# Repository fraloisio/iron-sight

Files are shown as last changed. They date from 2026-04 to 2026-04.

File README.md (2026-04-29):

# Iron Sight — Interactive Shooting Gallery

A museum installation where visitors aim a replica rifle at projected targets and pull the trigger. Infrared tracking detects where the gun is pointing and registers hits in a browser-based game. Designed for unattended operation in a public space.

**Created by:** Francesco Aloisio  
**Development assistance:** [Claude](https://claude.ai) (Anthropic)

---

## Table of Contents

1. [How It Works](#how-it-works)
2. [Hardware](#hardware)
3. [Wiring](#wiring)
4. [3D Files & Physical Assembly](#3d-files--physical-assembly)
5. [Space & Projector Setup](#space--projector-setup)
6. [Software Overview](#software-overview)
7. [Pi Setup](#pi-setup)
8. [Connection Modes](#connection-modes)
9. [First-Time Calibration](#first-time-calibration)
10. [Running the System](#running-the-system)
11. [Detection Parameters](#detection-parameters)
12. [Game Configuration](#game-configuration)

---

## How It Works

```
Wii IR bar (2 IR dots, fixed to projected surface)
  ↓  infrared light
Pi Camera v2 NoIR (inside rifle scope, points toward screen)
  ↓  picamera2 + OpenCV blob detection
Raspberry Pi Zero W2 (inside scope body)
  ↓  WebSocket JSON {x, y, shoot}  — port 8765
Browser game (shooting-gallery.html, any device on same network)
  ↓  moves crosshair, calls shoot() on trigger event
Projector → wall
```

The camera detects the two IR dots from the Wii bar and triangulates the midpoint. A homography transform (calibrated per installation) maps camera pixel coordinates to normalised screen coordinates [0–1]. The trigger microswitch sends a `shoot: true` flag via the same WebSocket message.

---

## Hardware

### Components

| Item | Model / Detail |
|---|---|
| Computer | Raspberry Pi Zero W2 |
| Camera | Raspberry Pi NoIR Camera Module v2.1 — 8 MP, 1080p, 75° FOV (IMX219 sensor) |
| IR emitter | Nintendo Wii sensor bar (OEM, USB-powered) |
| Laser pointer | KY-008 650 nm laser module (optional, used during calibration) |
| Trigger | Hinge Lever Micro Switch (NO contact wired to GPIO22) |
| Shutdown button | Momentary push button (wired to GPIO23 and GPIO3) |
| Rifle base | Gevær M/10 (Colt Canada C7 variant, Danish Army service rifle), decommissioned prop |
| Scope housing | 3D-printed faux scope — see `3d-files/` folder |
| Mounting | Picatinny rail system (rifle already had rails fitted) |
| Display | Projector — see [Space & Projector Setup](#space--projector-setup) |

> **Solenoid recoil:** A solenoid actuator was prototyped but removed from the final installation. The code in `ir_detect.py` still contains recoil logic (GPIO27). It is electrically harmless if nothing is wired to GPIO27, but set `RECOIL_ENABLED = False` at the top of `ir_detect.py` to suppress the GPIO output entirely.

---

## Wiring

All wires are soldered directly to the Pi Zero W2 GPIO header pins.

| Physical Pin | GPIO | Wire colour | Role |
|---|---|---|---|
| 2 | 5V | Red | (spare / future use) |
| 5 | GPIO3 | Yellow | Shutdown button — also hardware wake-from-halt |
| 6 | GND | Blue | Shared ground |
| 9 | GND | Green | Spare ground |
| 13 | GPIO27 | White | Recoil relay (unused — solenoid removed) |
| 14 | GND | Green | Trigger ground |
| 15 | GPIO22 | Brown | Trigger microswitch input |
| 16 | GPIO23 | Yellow | Shutdown button (software) |

### Microswitch wiring

| Microswitch terminal | Connects to |
|---|---|
| COM | Green wire → GND (Pin 14) |
| NO (Normally Open) | Brown wire → GPIO22 (Pin 15) |
| NC | Unconnected |

Pulling the trigger closes the NO contact, pulling GPIO22 LOW. The software uses an internal pull-up (`PUD_UP`) and triggers on `FALLING` edge with 120 ms debounce.

### Shutdown button

Two buttons both trigger shutdown. GPIO3 (Pin 5) has a hardware feature: pressing it also **powers the Pi back on** after a halt, so you can use the same button to turn on and off.

---

## 3D Files & Physical Assembly

All CAD and print files are in the `3d-files/` folder:

```
3d-files/
  *.3dm        Rhino source files (editable)
  *.stl        Print-ready STL files
  photos/      Assembly reference photos
```

### Assembly notes

- The scope body is 3D-printed in two halves that clamp around the Pi Zero W2.
- The **camera module** mounts flush at the **objective end** (the end pointing toward the screen/IR bar). The lens faces outward through a hole in the end cap.
- The **push button** (shutdown) mounts at the **eyepiece end** (the end facing the shooter).
- The assembled scope mounts onto the rifle's **Picatinny rail** using a standard rail clamp. No permanent modification to the rifle is required.
- Route the camera ribbon cable internally before closing the housing halves.
- The Pi's USB port (USB OTG) should remain accessible via a cutout for USB connection mode.

---

## Space & Projector Setup

These measurements were validated in the museum installation:

| Parameter | Value |
|---|---|
| Projector distance from wall | 3 m |
| Projector height (lens) | 60 cm from floor |
| Projected surface width | 1.65 m |
| Projected surface height | 1.02 m |
| Bottom edge of projected area | 1.65 m from floor |
| IR bar position | 25 cm below the top edge of the projected area, 60 cm from the top-right corner |
| Shooter position | 5.5 to 6 m from the wall, aligned with the centre of the projected area |

The current version of the software supports the IR bar placed either at the **top or bottom** of the projected area (not just the centre). Adjust the bar position and re-calibrate if the installation geometry differs.

> The IR bar should be USB-powered and fixed securely — any movement invalidates the calibration.

---

## Software Overview

### Files on the Pi (`~/`)

| File | Purpose |
|---|---|
| `ir_detect.py` | **Main process.** IR tracking + trigger + WebSocket server (port 8765). Run this during the game. |
| `preview.py` | **Calibration tool.** Live MJPEG preview at port 8080 with parameter sliders. Run this when setting up or re-calibrating. |
| `ironside-shutdown.py` | **Shutdown daemon.** Watches GPIO23 and GPIO3; halts the Pi on button press. Should always be running. |
| `ironside-portal.py` | **WiFi portal.** Runs when Pi is in hotspot mode; lets you connect the Pi to a WiFi network via a browser. |
| `calibration.json` | Homography matrix saved by `preview.py`. Loaded automatically by `ir_detect.py`. |
| `params.json` | Detection parameters saved by `preview.py`. Loaded automatically by `ir_detect.py`. |

### Files on the game device (laptop/Mac)

| File | Purpose |
|---|---|
| `shooting-gallery.html` | Main game — open in any browser |
| `config.js` | WebSocket connection config (Pi hostname and port). Edit this if the Pi's hostname or IP changes. |
| `ironside-manual.html` | Full operation manual. Serve locally with `python3 -m http.server 8080` to use the 3D viewer. |

`shooting-gallery.html` is fully self-contained — no server, no internet, no dependencies. Open directly in a browser.

### Architecture note

`ir_detect.py` and `ironside-shutdown.py` are independent processes. Run both in separate terminal sessions (or as systemd services — see [Running the System](#running-the-system)).

---

## Pi Setup

### OS

**Use Raspberry Pi OS Lite 32-bit** (not 64-bit).  
The 64-bit variant has a known NetworkManager bug that breaks WPA2 WiFi (`key-mgmt` negotiation fails). 32-bit works correctly.

Flash with Raspberry Pi Imager. Enable SSH and set hostname to `scope` in the imager's advanced options.

A pre-built image of a working installation is available at `archive/scope-backup-2026-04-28.img.gz`. Flash it directly — Raspberry Pi Imager can handle `.img.gz` without decompressing.

### Python dependencies

```bash
sudo apt update
sudo apt install -y python3-picamera2 python3-opencv python3-numpy python3-websockets
```

### Repository

```bash
git clone <repo-url>
# or copy the files manually via scp
```

The scripts expect to live in `~/` (home directory). `calibration.json` and `params.json` are read from the same directory as the script.

---

## Connection Modes

The Pi supports three connection modes. Choose based on what network infrastructure is available at the venue.

### Mode 1 — USB (simplest, no WiFi needed)

Connect the Pi to the game laptop with a USB **data** cable (Pi's USB OTG port, **not** the PWR port).

The Pi presents itself as a USB Ethernet adapter. Access the Pi at `scope.local` or `10.12.194.1`.

This mode requires USB gadget mode to be enabled in `/boot/config.txt` and `/boot/cmdline.txt`. See `ironside-manual.html` (Pi setup section) for the exact configuration steps.

### Mode 2 — WiFi (museum network)

Connect the Pi to the venue's WiFi. The Pi is reachable at `scope.local` on the same network.

To save a WiFi password onto the Pi:

```bash
sudo nmcli device wifi connect "SSID" password "password"
```

Or use Mode 3 (hotspot + portal) to do it from a browser without SSH.

### Mode 3 — Hotspot (Pi is the access point)

The Pi broadcasts its own WiFi network. The game laptop connects to it directly — no venue WiFi needed.

**Network:** `ironside`  
**Password:** `ironsight`  
**Pi address:** `10.42.0.1`

To activate the hotspot:

```bash
sudo nmcli connection up Hotspot
python3 ironside-portal.py  # optional: web UI to switch the Pi to a different WiFi
```

When the hotspot is active, navigate to `http://10.42.0.1` in a browser to get a portal page that lets you select a WiFi network and save credentials to the Pi (useful for switching from hotspot mode to museum WiFi mode without SSH).

> See `ironside-manual.html` for the full step-by-step network setup.

---

## First-Time Calibration

Calibration maps the camera's view to the projected screen. It must be done at the installation site with the projector on, the IR bar in place, and the rifle pointed at the screen.

1. Start the preview tool on the Pi:
   ```bash
   python3 preview.py
   ```

2. Open `http://scope.local:8080` in a browser on the game laptop.

3. Check the live feed — you should see two bright IR dots. If not, adjust **Exposure** down (try 1000–2000 µs) until ambient light is suppressed and only the IR dots are visible. Use **Dilation** to merge each dot cluster. **Save Params** when happy.

4. Aim the rifle at the **top-left** calibration target circle shown on the preview. Click **TOP-LEFT** in the browser.

5. Repeat for **TOP-RIGHT**, **BOTTOM-LEFT**, **BOTTOM-RIGHT**.

6. Click **SAVE CALIBRATION**. This writes `calibration.json`.

7. Stop `preview.py`. Start `ir_detect.py` (see below). The calibration loads automatically.

> Recalibrate if: the projector is moved, the IR bar is moved, or the scope is adjusted on the rail.

---

## Running the System

Both processes must be running during operation:

**Terminal 1 — Shutdown daemon:**
```bash
python3 ~/ironside-shutdown.py
```

**Terminal 2 — IR tracker + WebSocket:**
```bash
python3 ~/ir_detect.py
```

Then open `shooting-gallery.html` on the game laptop. The game connects to `ws://scope.local:8765` automatically.

### Optional: autostart on boot (recommended for museum deployment)

Create two systemd service files so the Pi starts the system without any manual steps after power-on.

**`/etc/systemd/system/ironside-shutdown.service`**
```ini
[Unit]
Description=Iron Sight shutdown button daemon
After=multi-user.target

[Service]
ExecStart=/usr/bin/python3 /home/admin/ironside-shutdown.py
Restart=always
User=admin

[Install]
WantedBy=multi-user.target
```

**`/etc/systemd/system/ironside.service`**
```ini
[Unit]
Description=Iron Sight IR tracker
After=network.target ironside-shutdown.service

[Service]
ExecStart=/usr/bin/python3 /home/admin/ir_detect.py
Restart=always
User=admin
WorkingDirectory=/home/admin

[Install]
WantedBy=multi-user.target
```

Enable both:
```bash
sudo systemctl daemon-reload
sudo systemctl enable ironside-shutdown.service ironside.service
sudo systemctl start ironside-shutdown.service ironside.service
```

---

## Detection Parameters

Accessible in `preview.py` at `http://scope.local:8080`. Changes apply live. Click **SAVE PARAMS** to persist — values are restored automatically on next startup.

| Parameter | Default | Effect |
|---|---|---|
| **Exposure (µs)** | 5000 | Sensor shutter time. Lower = darker image, isolates IR dots from ambient light. **This is the most important parameter.** Try 500–2000 µs for clean detection in lit environments. |
| **Gain** | 2.0 | Sensor amplification. Increase if IR dots are too faint at low exposure. |
| **Zoom** | 1.0 | Digital crop into the sensor frame. 1.0 = full 75° FOV. Recalibrate after changing. |
| **Dilation (px)** | 9 | Blob expansion before detection. Merges diffuse LED spots into solid clusters. Too high merges both clusters into one. |
| **Smoothing alpha** | 0.6 | EMA filter on crosshair position. 1.0 = instant (jittery). 0.1 = very smooth (laggy). |
| **Deadzone** | 0.004 | Minimum movement threshold (normalised 0–1). Prevents cursor drift when the rifle is held still. |
| **Max dot distance (px)** | 192 | Maximum pixel distance between the two IR clusters. Rejects false-positive pairs from other IR sources. |

**RESET** restores factory defaults without affecting the saved `params.json`.

---

## Game Configuration

`shooting-gallery.html` has a `CFG` object at the top of its `<script>` block. All timing, scoring, and gameplay parameters are set there.

The WebSocket address is set in `config.js` (not inside the HTML files) — update it there if the Pi's hostname or IP changes.

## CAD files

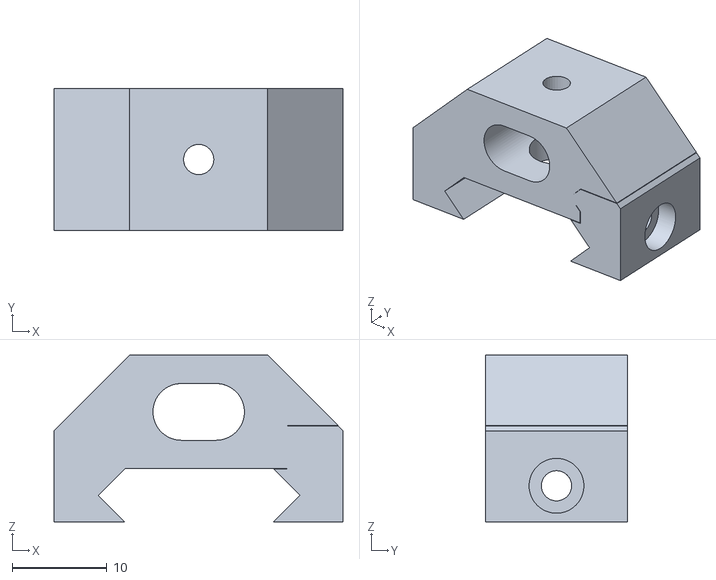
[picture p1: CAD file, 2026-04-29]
3d-files/Picatinny Clamp Assembled.stl
30.6 x 15.0 x 17.6

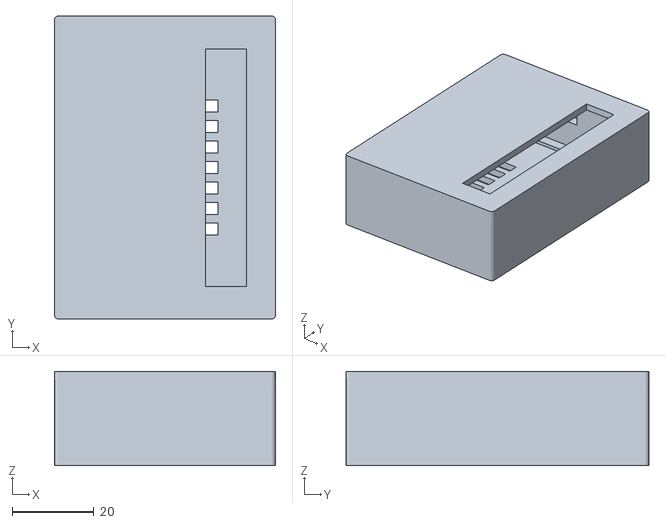
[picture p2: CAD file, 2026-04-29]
3d-files/Cables Enclosure Assembled.stl
54.0 x 74.0 x 23.0

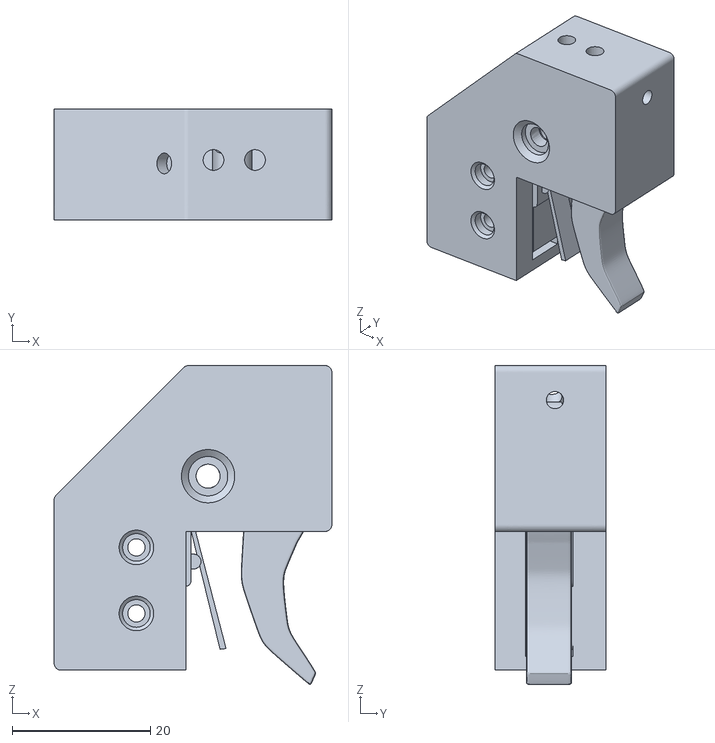
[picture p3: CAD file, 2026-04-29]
3d-files/Trigger Assembled.stl
40.2 x 16.0 x 46.1

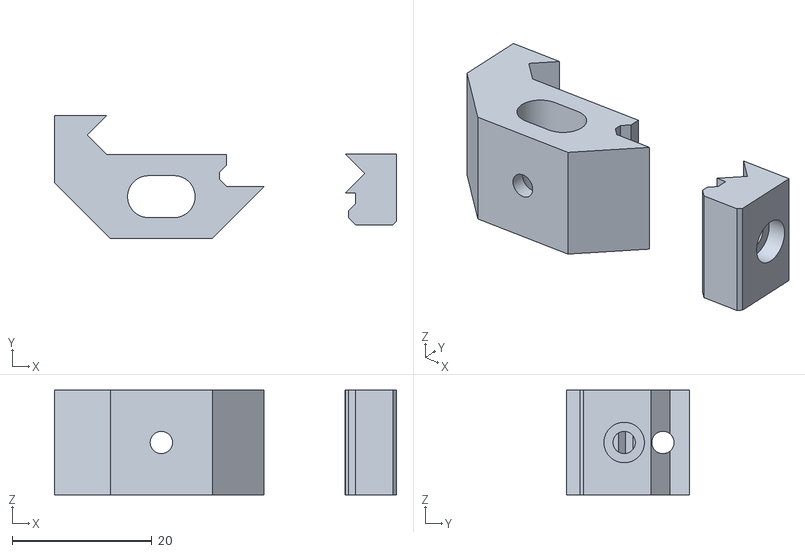
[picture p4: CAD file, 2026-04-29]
3d-files/Picatinny Clamp Parts.stl
49.0 x 17.6 x 15.0

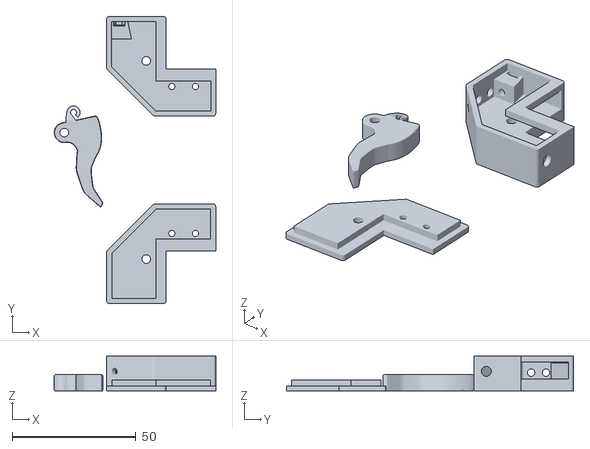
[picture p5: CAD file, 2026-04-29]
3d-files/Trigger Parts.stl
65.2 x 115.9 x 14.0

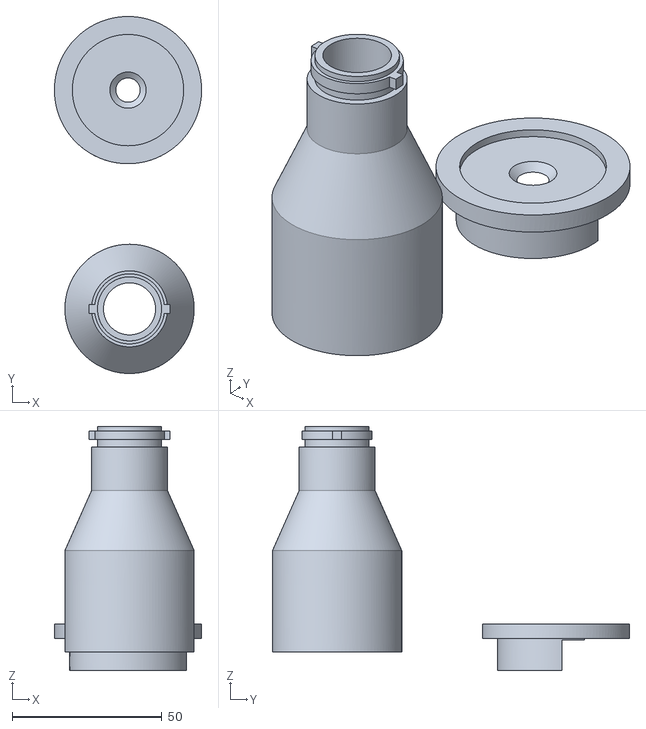
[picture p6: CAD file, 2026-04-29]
3d-files/Lens Enclosure and cap.stl
49.2 x 119.3 x 81.7

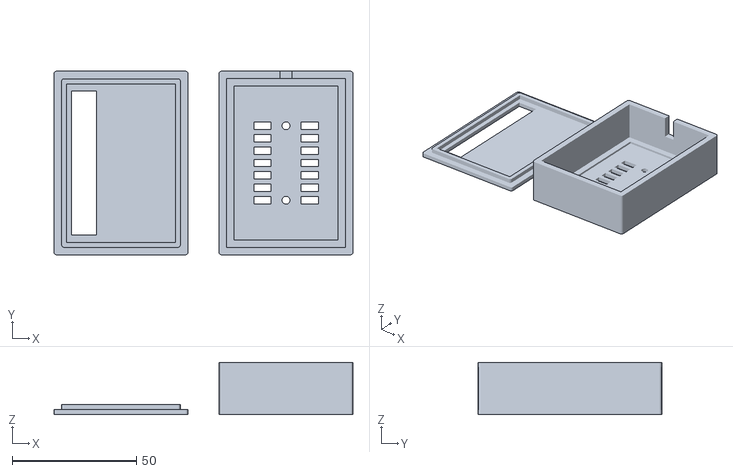
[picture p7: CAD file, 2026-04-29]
3d-files/Cables Enclosure Parts.stl
120.5 x 74.0 x 21.0

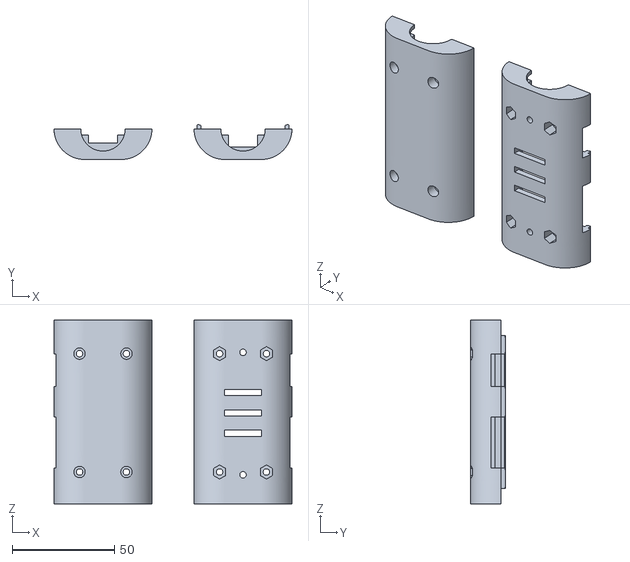
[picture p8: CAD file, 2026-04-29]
3d-files/Raspberry Pi Enclosure Parts.stl
116.6 x 17.1 x 90.0

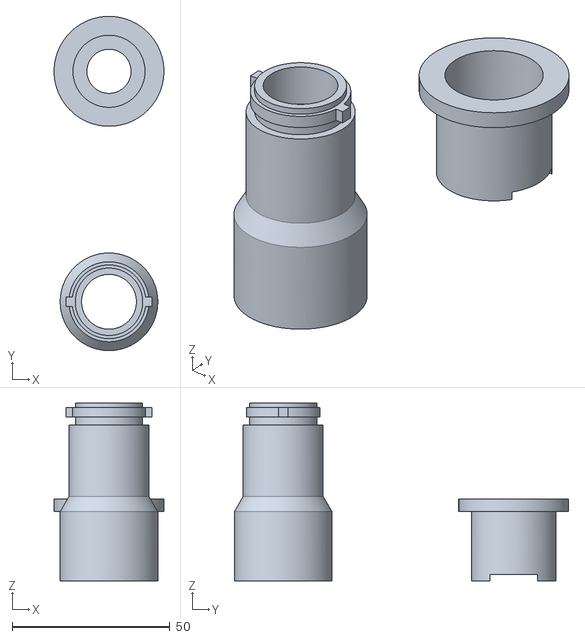
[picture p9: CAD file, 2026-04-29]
3d-files/Ocular Housing and cap.stl
34.9 x 106.1 x 56.5

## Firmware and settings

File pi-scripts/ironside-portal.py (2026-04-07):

#!/usr/bin/env python3
"""
Iron Sight — WiFi captive portal
Runs when hotspot is active. Access at http://10.42.0.1
"""
import subprocess
import time
import threading
from http.server import HTTPServer, BaseHTTPRequestHandler
from urllib.parse import parse_qs

def scan_networks():
    result = subprocess.run(
        ['nmcli', '-t', '-f', 'SSID,SIGNAL,SECURITY', 'device', 'wifi', 'list', '--rescan', 'yes'],
        capture_output=True, text=True
    )
    networks = []
    seen = set()
    for line in result.stdout.strip().split('\n'):
        parts = line.split(':')
        ssid = parts[0].strip()
        signal = parts[1].strip() if len(parts) > 1 else '0'
        security = parts[2].strip() if len(parts) > 2 else ''
        if ssid and ssid not in seen and ssid != 'ironside':
            seen.add(ssid)
            networks.append({'ssid': ssid, 'signal': signal, 'security': security})
    networks.sort(key=lambda x: int(x['signal']) if x['signal'].isdigit() else 0, reverse=True)
    return networks

def connect_wifi(ssid, password):
    subprocess.run(['nmcli', 'connection', 'down', 'Hotspot'], capture_output=True)
    result = subprocess.run(
        ['nmcli', 'device', 'wifi', 'connect', ssid, 'password', password],
        capture_output=True, text=True, timeout=30
    )
    return result.returncode == 0

HTML = """<!DOCTYPE html>
<html>
<head>
  <meta charset="UTF-8">
  <meta name="viewport" content="width=device-width, initial-scale=1.0">
  <title>Iron Sight — Add WiFi</title>
  <style>
    * { box-sizing: border-box; margin: 0; padding: 0; }
    body { font-family: -apple-system, BlinkMacSystemFont, sans-serif; background: #0f0f0f; color: #e0e0e0; padding: 24px; max-width: 480px; margin: 0 auto; }
    h1 { font-size: 1.3rem; color: #fff; margin-bottom: 6px; }
    .sub { color: #666; font-size: 0.85rem; margin-bottom: 20px; }
    .rescan { font-size: 0.8rem; color: #555; text-align: right; margin-bottom: 10px; cursor: pointer; text-decoration: underline; }
    .network { background: #1a1a1a; border: 1px solid #2a2a2a; border-radius: 8px; padding: 14px 16px; margin-bottom: 8px; cursor: pointer; display: flex; align-items: center; justify-content: space-between; }
    .network:hover, .network.selected { border-color: #4caf50; background: #1b3a1e; }
    .ssid { font-size: 0.95rem; }
    .meta { font-size: 0.75rem; color: #666; text-align: right; }
    .pwform { margin-top: 20px; display: none; }
    .pwform.visible { display: block; }
    .pwform label { font-size: 0.8rem; color: #888; display: block; margin-bottom: 6px; }
    .pwform input { width: 100%; background: #1a1a1a; border: 1px solid #2a2a2a; color: #e0e0e0; padding: 10px 14px; border-radius: 6px; font-size: 0.95rem; margin-bottom: 14px; outline: none; }
    .pwform input:focus { border-color: #4caf50; }
    button { width: 100%; background: #4caf50; color: #fff; border: none; padding: 12px; border-radius: 6px; font-size: 1rem; cursor: pointer; font-weight: 600; }
    button:hover { background: #43a047; }
    .msg { padding: 12px 16px; border-radius: 6px; margin-bottom: 16px; font-size: 0.9rem; }
    .msg.err { background: #3a1010; color: #f44336; border: 1px solid #f44336; }
  </style>
</head>
<body>
  <h1>Iron Sight — Add WiFi</h1>
  <p class="sub">Pick a network to save on the Pi</p>
  {message}
  <p class="rescan" onclick="location.reload()">↻ Rescan networks</p>
  <form method="POST" action="/connect">
    <input type="hidden" name="ssid" id="ssid_input">
    {networks_html}
    <div class="pwform" id="pwform">
      <label>Password for <strong id="ssid_label"></strong></label>
      <input type="password" name="password" id="pw" placeholder="WiFi password" autocomplete="new-password">
      <button type="submit">Connect &amp; Save</button>
    </div>
  </form>
  <script>
    document.querySelectorAll('.network').forEach(function(n) {
      n.addEventListener('click', function() {
        document.querySelectorAll('.network').forEach(function(x) { x.classList.remove('selected'); });
        n.classList.add('selected');
        document.getElementById('ssid_input').value = n.dataset.ssid;
        document.getElementById('ssid_label').textContent = n.dataset.ssid;
        document.getElementById('pwform').classList.add('visible');
        document.getElementById('pw').focus();
      });
    });
  </script>
</body>
</html>"""

CONNECTING_PAGE = """<!DOCTYPE html>
<html>
<head>
  <meta charset="UTF-8">
  <meta name="viewport" content="width=device-width, initial-scale=1.0">
  <title>Connecting…</title>
  <style>
    body {{ font-family: -apple-system, sans-serif; background: #0f0f0f; color: #e0e0e0; padding: 24px; max-width: 480px; margin: 0 auto; }}
    h1 {{ color: #fff; margin-bottom: 16px; }}
    .msg {{ padding: 16px; background: #1b3a1e; border: 1px solid #4caf50; border-radius: 8px; color: #4caf50; line-height: 1.6; }}
  </style>
</head>
<body>
  <h1>Connecting to {ssid}…</h1>
  <div class="msg">
    The Pi is connecting to <strong>{ssid}</strong>. This takes up to 30 seconds.<br><br>
    Once connected, the <strong>ironside</strong> hotspot will disappear.<br>
    Reconnect your device to <strong>{ssid}</strong> and SSH in as normal.
  </div>
</body>
</html>"""


class PortalHandler(BaseHTTPRequestHandler):
    def log_message(self, format, *args):
        pass

    def render(self, networks, message=''):
        nets_html = ''
        for n in networks:
            lock = '🔒 ' if n['security'] and n['security'] not in ('', '--') else ''
            sig = n['signal'] + '%' if n['signal'].isdigit() else '?'
            nets_html += f'<div class="network" data-ssid="{n["ssid"]}"><span class="ssid">{lock}{n["ssid"]}</span><span class="meta">{sig}</span></div>\n'
        html = HTML.replace('{networks_html}', nets_html).replace('{message}', message)
        self.send_response(200)
        self.send_header('Content-Type', 'text/html; charset=utf-8')
        self.end_headers()
        self.wfile.write(html.encode())

    def do_GET(self):
        if self.path != '/':
            self.send_response(302)
            self.send_header('Location', 'http://10.42.0.1/')
            self.end_headers()
            return
        self.render(scan_networks())

    def do_POST(self):
        length = int(self.headers.get('Content-Length', 0))
        body = self.rfile.read(length).decode()
        params = parse_qs(body)
        ssid = params.get('ssid', [''])[0]
        password = params.get('password', [''])[0]

        if not ssid or not password:
            self.render(scan_networks(), '<div class="msg err">Select a network and enter a password.</div>')
            return

        # Send response immediately, then connect in background
        page = CONNECTING_PAGE.format(ssid=ssid)
        self.send_response(200)
        self.send_header('Content-Type', 'text/html; charset=utf-8')
        self.end_headers()
        self.wfile.write(page.encode())

        def do_connect():
            time.sleep(0.5)
            connect_wifi(ssid, password)

        threading.Thread(target=do_connect, daemon=True).start()


if __name__ == '__main__':
    print('Iron Sight portal running at http://10.42.0.1')
    HTTPServer(('0.0.0.0', 80), PortalHandler).serve_forever()

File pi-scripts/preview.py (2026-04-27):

"""
Iron Sight — Live Preview + Browser Calibration
Streams annotated camera feed and runs calibration from the browser.

  python3 preview.py

Open on your Mac:  http://scope.local:8080
"""

import cv2
import numpy as np
import time
import json
import os
import threading
from http.server import BaseHTTPRequestHandler, ThreadingHTTPServer
from urllib.parse import urlparse, parse_qs
from picamera2 import Picamera2

FRAME_W, FRAME_H = 320, 240
CAL_PATH    = os.path.join(os.path.dirname(os.path.abspath(__file__)), 'calibration.json')
PARAMS_PATH = os.path.join(os.path.dirname(os.path.abspath(__file__)), 'params.json')
M = 0.2

latest_jpeg = None
frame_lock  = threading.Lock()

cal_points = {}
cal_lock   = threading.Lock()

smooth = {'x': 160.0, 'y': 120.0}
smooth_bright = {'v': 200.0}

# ── Tunable params (live, no restart needed) ──────────────
FACTORY_DEFAULTS = {
    'exposure':     5000,
    'gain':         2.0,
    'zoom':         1.0,
    'min_bright':   180,
    'dilation':     9,
    'alpha':        0.6,
    'deadzone':     0.004,
    'max_dot_dist': 192,
}
params = dict(FACTORY_DEFAULTS)
if os.path.exists(PARAMS_PATH):
    with open(PARAMS_PATH) as f:
        params.update(json.load(f))
    print(f'Params loaded from {PARAMS_PATH}')
params_lock   = threading.Lock()
camera_ref    = {'picam2': None, 'base_crop': None}
apply_camera  = threading.Event()  # set when exposure/gain need updating


def apply_zoom_crop(picam2, zoom):
    try:
        base = camera_ref['base_crop']
        if base is None:
            return
        bx, by, bw, bh = base
        cw = int(bw / zoom)
        ch = int(bh / zoom)
        x  = bx + (bw - cw) // 2
        y  = by + (bh - ch) // 2
        picam2.set_controls({'ScalerCrop': (x, y, cw, ch)})
    except Exception as e:
        print(f'ScalerCrop failed: {e}')

# live stats for the UI
stats = {'bright': 0, 'blobs': 0, 'locked': False}
stats_lock = threading.Lock()


def find_clusters(gray):
    with params_lock:
        min_bright    = params['min_bright']
        dilation      = params['dilation']
        max_dot_dist  = params['max_dot_dist']

    brightest = int(gray.max())
    with stats_lock:
        stats['bright'] = brightest

    if brightest < min_bright:
        with stats_lock:
            stats['blobs'] = 0
            stats['locked'] = False
        return None, brightest

    smooth_bright['v'] = 0.1 * brightest + 0.9 * smooth_bright['v']
    threshold = int(smooth_bright['v'] * 0.75)
    _, thresh = cv2.threshold(gray, threshold, 255, cv2.THRESH_BINARY)

    kernel  = cv2.getStructuringElement(cv2.MORPH_ELLIPSE, (dilation, dilation))
    dilated = cv2.dilate(thresh, kernel)

    contours, _ = cv2.findContours(dilated, cv2.RETR_EXTERNAL, cv2.CHAIN_APPROX_SIMPLE)

    blobs = []
    for c in contours:
        area = cv2.contourArea(c)
        if area < 10 or area > 2000:
            continue
        M_m = cv2.moments(c)
        if M_m['m00'] > 0:
            cx = int(M_m['m10'] / M_m['m00'])
            cy = int(M_m['m01'] / M_m['m00'])
            blobs.append((area, cx, cy))

    with stats_lock:
        stats['blobs'] = len(blobs)
        stats['locked'] = len(blobs) >= 2

    if len(blobs) < 2:
        return None, brightest

    blobs.sort(reverse=True)
    top2 = sorted(blobs[:2], key=lambda b: b[1])
    _, lx, ly = top2[0]
    _, rx, ry = top2[1]
    dist = ((rx - lx) ** 2 + (ry - ly) ** 2) ** 0.5
    if dist > max_dot_dist:
        with stats_lock:
            stats['blobs'] = len(blobs)
            stats['locked'] = False
        return None, brightest
    mid = ((lx + rx) // 2, (ly + ry) // 2)
    return (lx, ly), (rx, ry), mid, brightest


def camera_loop():
    global latest_jpeg, smooth
    picam2 = Picamera2()
    picam2.configure(picam2.create_video_configuration(
        main={"size": (FRAME_W, FRAME_H), "format": "RGB888"},
        sensor={"output_size": (1640, 1232), "bit_depth": 10},
        buffer_count=2, queue=False
    ))
    picam2.start()
    with params_lock:
        picam2.set_controls({"AeEnable": False,
                              "ExposureTime": params['exposure'],
                              "AnalogueGain": params['gain']})
        zoom = params['zoom']
    time.sleep(0.5)
    meta = picam2.capture_metadata()
    camera_ref['base_crop'] = meta.get('ScalerCrop')
    camera_ref['picam2'] = picam2
    apply_zoom_crop(picam2, zoom)
    time.sleep(0.5)

    while True:
        # Apply camera setting changes if requested
        if apply_camera.is_set():
            apply_camera.clear()
            with params_lock:
                picam2.set_controls({"AeEnable": False,
                                     "ExposureTime": params['exposure'],
                                     "AnalogueGain": params['gain']})
                zoom = params['zoom']
            apply_zoom_crop(picam2, zoom)

        with params_lock:
            alpha = params['alpha']

        frame_rgb = picam2.capture_array()
        frame     = cv2.cvtColor(frame_rgb, cv2.COLOR_RGB2BGR)
        gray      = cv2.cvtColor(frame_rgb, cv2.COLOR_RGB2GRAY)

        result = find_clusters(gray)
        if result[0] is not None:
            left_c, right_c, raw_mid, brightest = result
            cv2.circle(frame, left_c,  14, (0, 255, 0), 2)
            cv2.circle(frame, right_c, 14, (0, 255, 0), 2)
            cv2.line(frame, left_c, right_c, (0, 220, 0), 1)
            smooth['x'] = alpha * raw_mid[0] + (1 - alpha) * smooth['x']
            smooth['y'] = alpha * raw_mid[1] + (1 - alpha) * smooth['y']
            mid = (int(smooth['x']), int(smooth['y']))
            cv2.drawMarker(frame, mid, (0, 80, 255), cv2.MARKER_CROSS, 28, 2)
            cv2.circle(frame, mid, 10, (0, 80, 255), 1)
            cv2.putText(frame, f'aim ({mid[0]/FRAME_W:.3f}, {mid[1]/FRAME_H:.3f})',
                        (10, FRAME_H - 10), cv2.FONT_HERSHEY_SIMPLEX, 0.4, (0, 80, 255), 1)
            cv2.putText(frame, f'bright:{brightest}  LOCKED',
                        (10, 14), cv2.FONT_HERSHEY_SIMPLEX, 0.4, (0, 255, 100), 1)
        else:
            brightest = result[1]
            cv2.putText(frame, f'bright:{brightest}  no IR bar',
                        (10, 14), cv2.FONT_HERSHEY_SIMPLEX, 0.4, (0, 100, 255), 1)

        # Draw calibration targets
        targets = {
            'tl': (int(M * FRAME_W),        int(M * FRAME_H)),
            'tr': (int((1-M) * FRAME_W),    int(M * FRAME_H)),
            'br': (int((1-M) * FRAME_W),    int((1-M) * FRAME_H)),
            'bl': (int(M * FRAME_W),         int((1-M) * FRAME_H)),
        }
        with cal_lock:
            pts = dict(cal_points)
        for key, (tx, ty) in targets.items():
            colour = (0, 255, 0) if key in pts else (255, 255, 255)
            filled = -1 if key in pts else 2
            cv2.circle(frame, (tx, ty), 10, colour, filled)
            cv2.drawMarker(frame, (tx, ty), colour, cv2.MARKER_CROSS, 24, 2)
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

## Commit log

2026-03-27 Add config.js — single file for IP/host config
    piHost and wsPort now live in config.js next to the HTML.
    No need to touch shooting-gallery.html when the Pi IP changes.
2026-03-27 Add 6-dot clustering, homography calibration, and pi-scripts folder
    ir_detect.py: groups IR dots into left/right clusters by x position,
    uses cluster centroids for stable aim tracking, applies homography
    transform if calibration.json exists.
    calibrate.py: 4-corner wizard — aim rifle at each screen corner,
    press ENTER, saves perspective transform to calibration.json.
    Handles 2 or 6 IR dots automatically via clustering.
2026-03-27 Switch camera capture from rpicam-vid pipe to picamera2
    rpicam-vid MJPEG stdout piping was unreliable on Pi Zero W2.
    All three scripts now use picamera2 directly — cleaner, faster,
    no subprocess buffering issues.
    [ir_detect.py]
2026-03-27 Improve dot detection reliability for calibration
    - Lock camera exposure (2ms shutter, gain 1.0) to suppress ambient light
    and keep IR dot brightness consistent across all aim angles
    - Adaptive threshold (80% of brightest pixel) instead of fixed 200
    - Live dot count display during calibration so you know when dots are
    visible before pressing Enter
    [ir_detect.py]
2026-03-27 Add live camera preview streamed to browser
    preview.py serves MJPEG stream on port 8080 with IR dots annotated:
    yellow circles on raw dots, green circles on cluster centroids,
    red dot on midpoint, aim coordinates and brightness info overlaid.
    Open http://fraspberry.local:8080 on Mac while running on Pi.
2026-03-27 Use inset calibration points to keep both IR dots in frame
    Extreme corner angles cause one dot to leave the camera FOV.
    Calibration points are now 20% inset from each corner — both dots
    remain visible at these angles, homography extrapolates to true edges.
2026-03-27 Fix calibration retry logic and increase exposure
    - Retry loop now stays on the same corner until capture succeeds
    (was incorrectly advancing to next corner on failure)
    - Exposure increased to 5ms / gain 2.0 for better dot visibility
2026-03-27 Browser-based calibration in preview.py + smoothing
    preview.py now serves a calibration UI at /. Aim at each corner,
    click its button to capture, then Save — no terminal switching needed.
    Captured points shown as cross markers on the live feed.
    Both preview.py and ir_detect.py now use EMA smoothing (alpha=0.25)
    to reduce midpoint jitter.
    [ir_detect.py, preview.py]
2026-03-27 Switch to 16:9 capture resolution (640x360)
    Camera was capturing 4:3 (640x480), TV is 16:9. Preview looked
    squished compared to the projected screen, making calibration
    confusing. 640x360 matches TV proportions exactly.
    Delete calibration.json on the Pi before recalibrating.
2026-03-27 Make preview fullscreen with buttons overlaid
    Stream now fills the entire browser window. Calibration buttons
    float at the bottom over the video. No more tiny box in the middle.
2026-03-27 Rework IR detection: dilate to merge LED clusters into 2 blobs
    Old approach detected 6 individual dots and tried to split them —
    unreliable when count varied and threshold fluctuated.
    New approach:
    - Threshold at 75% of max brightness (requires bright:180+ to even try)
    - Dilate with 18px ellipse kernel to merge 3 LEDs per side into 1 blob
    - Find 2 largest blobs, sort left/right, compute midpoint
    - Cleaner display: green circles on clusters, orange crosshair on aim
    Same logic in both preview.py and ir_detect.py.
    [ir_detect.py, preview.py]
2026-03-27 Fix ir_detect crash + clear calibration UI feedback
    ir_detect.py: remove stale reference to 'dots' variable (NameError crash)
    preview.py: calibration buttons turn green with coordinates on success,
    red error message on failure, status bar always visible at top of screen,
    save button changes to green tick when written successfully.
    [ir_detect.py, preview.py]
2026-03-27 Fix hanging buttons and cursor not moving
    preview.py: switch to ThreadingHTTPServer so /capture and /save
    requests are handled in parallel with the MJPEG stream — single
    threaded server was blocking all requests while streaming.
    ir_detect.py: sync exposure to 5ms/gain 2.0 to match preview.py
    so dot detection behaves identically in both scripts.
    [ir_detect.py, preview.py]
2026-03-27 Map inset calibration points to full screen corners
    Homography destination was (0.2,0.2)-(0.8,0.8), so crosshair only
    moved in 60% of the screen. Now maps to (0,0)-(1,1) — user aims at
    the 20% inset positions (stable IR detection) but the math treats
    them as the true screen corners, giving full range of motion.
    Recalibrate after this change (rm calibration.json, run preview.py).
2026-03-28 Save working calibration
    Homography matrix from 4-corner calibration at 2.3m distance,
    IR bar at top of TV, 640x360 frame, inset points mapped to full corners.
2026-04-05 Optimise IR detection pipeline and add live tuning UI
    - Drop capture resolution to 320x180 (was 640x360) — dilation 18x faster
    - Add live parameter sliders in preview.py (exposure, gain, min_bright, dilation, alpha)
    - Add live stats panel (brightness, blob count, lock status)
    - Add Save Params button — persists settings to params.json, auto-loaded on restart
    - Add Reset calibration button
    - Smooth brightness threshold with EMA to reduce crosshair flicker
    - Revert downscale-before-dilate (broke detection at 160x90)
    - Update config.js Pi IP to 192.168.0.178
    [benchmark.py, ir_detect.py, preview.py]
2026-04-05 Update preview.py hostname to fraspberry2 and fix USB gadget SSH config
    [preview.py]
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2026-04-06 Fix script paths in guide — scripts are in home dir not pi-scripts/
2026-04-06 Add WiFi captive portal — served at http://10.42.0.1 when hotspot is active
2026-04-06 MVP complete — captive portal, USB gadget, hotspot fallback all working
    What works at this tag:
    - IR tracking at 29fps (320x180, 9px dilation kernel)
    - WebSocket broadcast to browser game via fraspberry2.local on all connection modes
    - Three connection modes: WiFi, USB gadget, hotspot fallback
    - Captive portal on hotspot (auto-redirect, network picker, saves new WiFi)
    - Live param tuning via preview.py browser UI (sliders, save to params.json)
    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
2026-04-07 Add trigger (GPIO22) and shutdown button (GPIO3) to ir_detect.py
    - GPIO22 (beige): microswitch trigger, sets shoot=True on falling edge
    - GPIO3 (orange): shutdown button, runs shutdown now on press
    - shoot resets to False after each broadcast cycle
    [ir_detect.py]
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2026-04-07 Fix portal: tear down hotspot before connecting to new WiFi
    [ironside-portal.py]
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2026-04-09 Add recoil relay (GPIO27) and run it in separate thread from camera loop
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2026-04-12 320x240 resolution, params.json in ir_detect, dual shutdown btn, Danish UI
    - Camera resolution bumped 320x180 → 320x240 in ir_detect.py and preview.py
    - ir_detect.py now loads params.json on startup (dilation, alpha, min_bright, max_dot_dist)
    - max_dot_dist exposed as tunable param (was hardcoded 60% of frame width)
    - ironside-shutdown.py watches both GPIO23 and GPIO3 (GPIO3 = hardware wake-from-halt)
    - shooting-gallery.html: font → Allerta Stencil, UI text localised to Danish
    - Add IR-camera-trigger-recoil_firmware.ino and iron-sight-todo.html
    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
2026-04-14 Preview UI overhaul: full-FOV sensor mode, zoom/deadzone sliders, tooltips, panel collapse, persist params on reload
    - ir_detect.py: full-FOV sensor mode (1640x1232), deadzone param, calibration resolution scaling
    - preview.py: FACTORY_DEFAULTS + /params + /resetparams endpoints, zoom slider with ScalerCrop,
    deadzone slider, ⓘ tooltips (JS fixed-position), expand/collapse panel, loadParams() on
    DOMContentLoaded so sliders always reflect last-saved params.json on page load
    [ir_detect.py, preview.py]
2026-04-27 Update README and connection guide for museum-ready documentation
    - README: full rewrite — hardware list, wiring, assembly, space measurements,
    software overview, Pi setup, connection modes, calibration workflow,
    systemd autostart service files, parameter reference; rifle identified as Gevær M/10
    - ironside-guide.html: fix shooting distance (3-4m → 5.5-6m), add shutdown daemon
    to startup steps, update deadzone/zoom in field notes, refresh backup date
2026-04-27 Rename Pi hostname from fraspberry2 to scope; remove personal WiFi credentials
    - Replace all instances of fraspberry2 → scope across README, ironside-guide, preview.py
    - ironside-guide: remove ICO-860CAD network name and 192.168.0.178 static IP
    - ironside-guide: add SSH credentials (admin/ironsight) to subtitle and Option A
    - ironside-guide: update Option A to be venue-agnostic (no specific network name)
    - ironside-guide: update backup filename to scope-backup.img.gz
    [preview.py]
2026-04-27 Archive unused files; disable recoil; gitignore archive folder
    - Moved to archive/SAFE-TO-DELETE (gitignored, kept locally):
    calibrate.py, test_dots.py, setup_hotspot.sh,
    iron-sight-todo.html, IR-camera-trigger-recoil_firmware.ino
    - Moved to archive/ (gitignored): dead-eye.html (working alt game, not deployed)
    - ir_detect.py: set RECOIL_ENABLED = False (solenoid removed from installation)
    - .gitignore: added archive/ rule
2026-04-27 Add ironside-manual.html — full operation manual with light wiki design
    Covers: requirements, device startup, WiFi portal, SSH connection,
    calibration workflow, IR detection, game startup, troubleshooting (8 scenarios),
    and assembly placeholder. Image placeholders throughout for photos/screenshots.
2026-04-27 Manual v2: overview section, WiFi explanation, params table, laser calibration, image slots
    - New "How it works" section: parts grid, IR tracking explained for general public
    - Game screenshot placeholder added after overview
    - Requirements: checkmarks → dashes, expanded WiFi firewall explanation, added
    power bank, USB charger, projector to requirements list
    - Starting device: "scope" → "rifle scope" throughout; steps 4/5/6 use img tags
    pointing to images/wifi-a.png, wifi-b.png, wifi-c.png with fallback placeholders
    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
2026-04-27 Add images folder; wire all photos into manual
    - images/: power-port.jpg, yellow-button.jpg, green-led.jpg, preview-locked.jpg,
    wifi-a.png, wifi-b.jpg, wifi-c.jpg (renamed from user-supplied files)
    - ironside-manual.html: replaced all placeholder divs with real <img> tags
    and captions; fixed wifi-b/c extensions from .png to .jpg
2026-04-27 Manual v3: overview rewrite, quick start, blobs/OpenCV language, image wiring
    - images/: renamed splash-screen.jpg, game-screenshot.jpg, wifi-a.jpg; removed wifi-a-fallback
    - Overview: mention NoIR camera + OpenCV in intro; remove false "no radio signals" paragraph;
    update tracking description (blobs, centroids, perspective transform); add splash/game/components images
    - Requirements: remove components image placeholder
    - Starting device: wifi-a.png → wifi-a.jpg; "captive portal" used correctly
    - Calibration: "dots" → "blobs" with explanation of 3 LEDs per cluster;
    laser pointer made optional with alternatives; removed calibration screenshot placeholder
    - New Quick Start section (ret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
2026-04-29 Update README, add 3D files and Three.js viewer, remove manual from tracking
    - README: fix IR bar position, USB IP, dead-eye.html refs, add laser pointer,
    backup image path, config.js; replace handover.docx refs with manual
    - .gitignore: exclude ironside-manual.html and Images/ from repo
    - Untrack ironside-manual.html (kept locally)
    - Remove iron-sight-handover.docx and ironside-guide.html
    - Add 3d-files/ (STL + Rhino source for all scope parts)
    - Add js/ (Three.js r128, STLLoader, OrbitControls for offline 3D viewer)
    [Cables Enclosure Assembled.stl, Cables Enclosure Parts.stl, Lens Enclosure and cap.stl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]
